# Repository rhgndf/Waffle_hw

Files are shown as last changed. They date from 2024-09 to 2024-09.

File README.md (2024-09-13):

# Waffle: a pocket pager, LoRA transceiver and RF experimentation platform
Hardware designs for Waffle, a compact Pager and general RF multitool.

## Introduction
This is a reboot of a [project started in 2016](https://hackaday.io/project/11056-waffle-a-pocket-sized-digital-radio-system), aimed at creating a pocket-sized digital radio system. Due to a lack of clear objectives and motivation, this project never got any further. However, there is today a certain revival of POCSAG in the amateur radio community, with the [DAPNET project](http://hampager.de). No open-source pager design exist to this day. This project aims to bridge that gap, and bring an open design that could be adapted to anyone's needs. 

## Feature list

 - UHF (430-440) support
 - User interface with three buttons and an easy-to-read display
 - Programmable either via the display, or via Wifi and web portal. 

## Hardware
Uses an ESP32-S3, coupled with an SX1276 for reception and transmission of signals. Battery is a classic 3.7V Li-Ion cell with integrated battery management and charging. USB-C port for programming and charging. OLED or LCD display (TBD).

## Hardware revision list

 - The [initial design from 2016](https://hackaday.io/project/11056-waffle-a-pocket-sized-digital-radio-system) is known as rev XX
 - 0.1a: current version. Aims to validate the basic hardware choices and being dev on software.

## Software
The (WIP) software can be found in [this repository](https://github.com/Jankyneering/Waffle_sw).

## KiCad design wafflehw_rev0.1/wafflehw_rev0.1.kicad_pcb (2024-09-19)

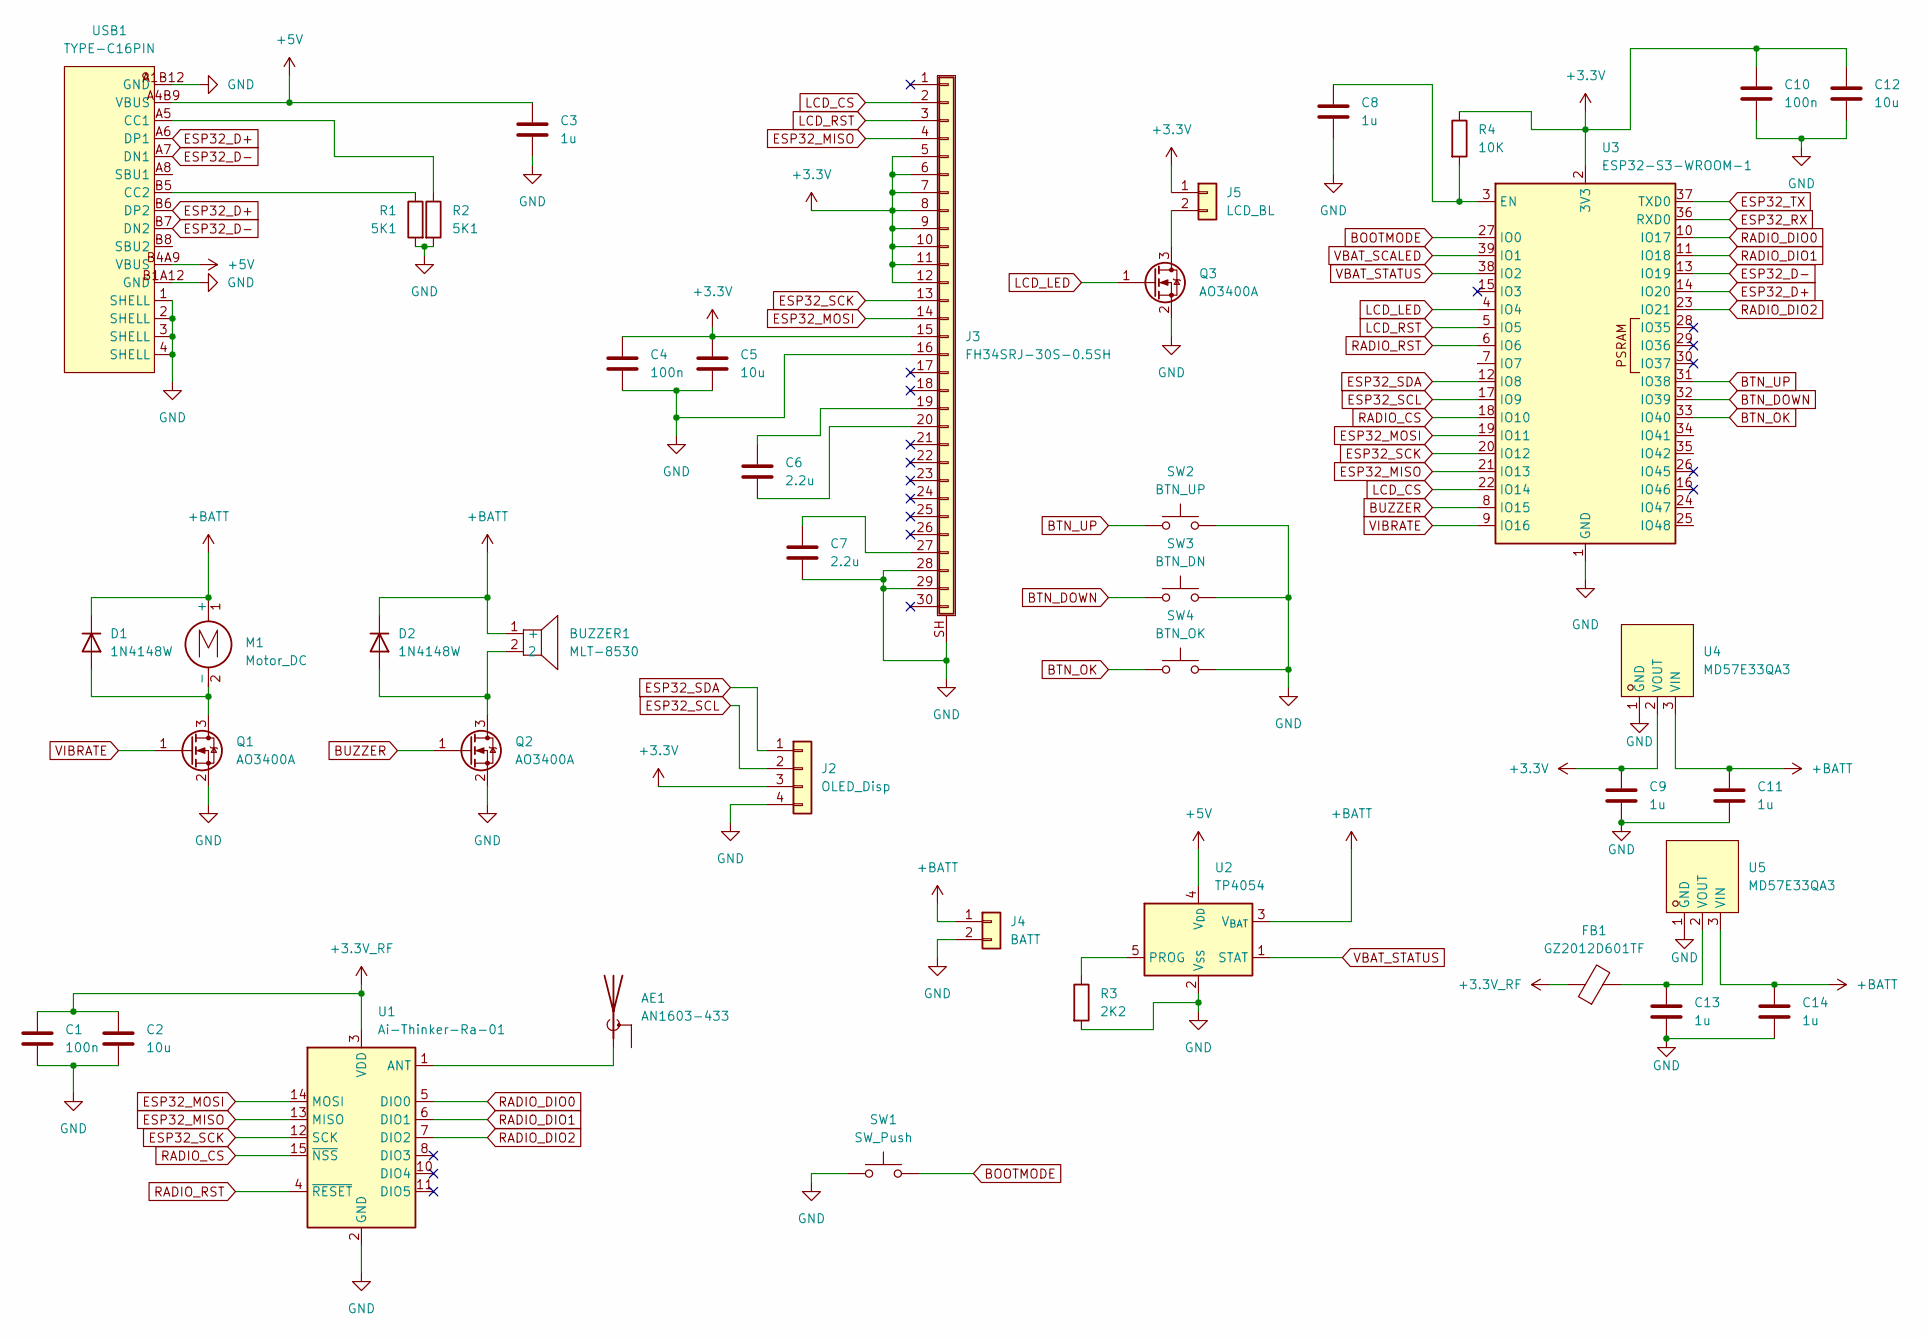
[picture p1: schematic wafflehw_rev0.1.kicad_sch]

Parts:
AE1: AN1603-433; Coilcraft_MA5532-AE_RFID
BUZZER1: MLT-8530; BUZ-SMD_4P-L8.5-W8.5-P8.50-BR; LCSC Part C94599
C1, C4, C10: 100n; C_0805_2012Metric
C2, C5, C12: 10u; C_0805_2012Metric
C3, C8, C9, C11, C13, C14: 1u; C_0805_2012Metric
C6, C7: 2.2u; C_0805_2012Metric
D1, D2: 1N4148W; D_SOD-123
FB1: GZ2012D601TF; L_0805_2012Metric
J2: OLED_Disp; PinHeader_1x04_P2.54mm_Vertical
J3: FH34SRJ-30S-0.5SH; ER-CON30HB-1
J4: BATT; ER-CON2.0-2P-SMD
J5: LCD_BL; ER-CON2.0-2P-SMD
M1: Motor_DC
Q1, Q2, Q3: AO3400A; SOT-23
R1, R2: 5K1; C_0805_2012Metric
R3: 2K2; C_0805_2012Metric
R4: 10K; C_0805_2012Metric
SW1: SW_Push; SW_SPST_CK_RS282G05A3
SW2: BTN_UP; SW_SPST_CK_RS282G05A3
SW3: BTN_DN; SW_SPST_CK_RS282G05A3
SW4: BTN_OK; SW_SPST_CK_RS282G05A3
U1: Ai-Thinker-Ra-01; Ai-Thinker-Ra-01-LoRa
U2: TP4054; SOT-23-5
U3: ESP32-S3-WROOM-1
U4, U5: MD57E33QA3; SOT-23-3_L2.9-W1.6-P1.90-LS2.8-BR; LCSC Part C920553
USB1: TYPE-C16PIN; USB-C-SMD_TYPE-C16PIN; LCSC Part C393939

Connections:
+3.3V: C4.1, C5.1, C9.1, C10.1, C12.1, J2.3, J3.5, J3.6, J3.7, J3.8, J3.9, J3.10, J3.11, J3.12, J3.15, J5.1, R4.1, U3.2 (3V3), U4.2 (VOUT)
+3.3V_RF: C1.1, C2.1, FB1.1, U1.3 (VDD)
+5V: C3.1, U2.4 (V_{DD}), USB1.A4B9 (VBUS), USB1.B4A9 (VBUS)
+BATT: BUZZER1.1 (+), C11.1, C14.1, D1.1 (K), D2.1 (K), J4.1, M1.1 (+), U2.3 (V_{BAT}), U4.3 (VIN), U5.3 (VIN)
BOOTMODE: SW1.2, U3.27 (IO0)
BTN_DOWN: SW3.1, U3.32 (IO39)
BTN_OK: SW4.1, U3.33 (IO40)
BTN_UP: SW2.1, U3.31 (IO38)
BUZZER: Q2.1 (G), U3.8 (IO15)
ESP32_D+: U3.14 (IO20), USB1.A6 (DP1), USB1.B6 (DP2)
ESP32_D-: U3.13 (IO19), USB1.A7 (DN1), USB1.B7 (DN2)
ESP32_MISO: J3.4, U1.13 (MISO), U3.21 (IO13)
ESP32_MOSI: J3.14, U1.14 (MOSI), U3.19 (IO11)
ESP32_RX: U3.36 (RXD0)
ESP32_SCK: J3.13, U1.12 (SCK), U3.20 (IO12)
ESP32_SCL: J2.2, U3.17 (IO9)
ESP32_SDA: J2.1, U3.12 (IO8)
ESP32_TX: U3.37 (TXD0)
GND: C1.2, C2.2, C3.2, C4.2, C5.2, C7.2, C8.2, C9.2, C10.2, C11.2, C12.2, C13.2, C14.2, J2.4, J3.16, J3.28, J3.29, J3.SH (Shield), J4.2, Q1.2 (S), Q2.2 (S), Q3.2 (S), R1.2, R2.2, R3.2, SW1.1, SW2.2, SW3.2, SW4.2, U1.2 (GND), U1.9 (GND), U1.16 (GND), U2.2 (V_{SS}), U3.1 (GND), U3.40 (GND), U3.41 (GND), U4.1 (GND), U5.1 (GND), USB1.1 (SHELL), USB1.2 (SHELL), USB1.3 (SHELL), USB1.4 (SHELL), USB1.A1B12 (GND), USB1.B1A12 (GND)
LCD_CS: J3.2, U3.22 (IO14)
LCD_LED: Q3.1 (G), U3.4 (IO4)
LCD_RST: J3.3, U3.5 (IO5)
unnamed: AE1.1 (A), U1.1 (ANT)
unnamed: D1.2 (A), M1.2 (-), Q1.3 (D)
unnamed: BUZZER1.2, D2.2 (A), Q2.3 (D)
unnamed: C6.1, J3.19
unnamed: C6.2, J3.20
unnamed: C7.1, J3.27
unnamed: J5.2, Q3.3 (D)
unnamed: R3.1, U2.5 (PROG)
unnamed: C8.1, R4.2, U3.3 (EN)
unnamed: C13.1, FB1.2, U5.2 (VOUT)
unnamed: R2.1, USB1.A5 (CC1)
unnamed: R1.1, USB1.B5 (CC2)
RADIO_CS: U1.15 (~NSS), U3.18 (IO10)
RADIO_DIO0: U1.5 (DIO0), U3.10 (IO17)
RADIO_DIO1: U1.6 (DIO1), U3.11 (IO18)
RADIO_DIO2: U1.7 (DIO2), U3.23 (IO21)
RADIO_RST: U1.4 (~RESET), U3.6 (IO6)
VBAT_SCALED: U3.39 (IO1)
VBAT_STATUS: U2.1 (STAT), U3.38 (IO2)
VIBRATE: Q1.1 (G), U3.9 (IO16)

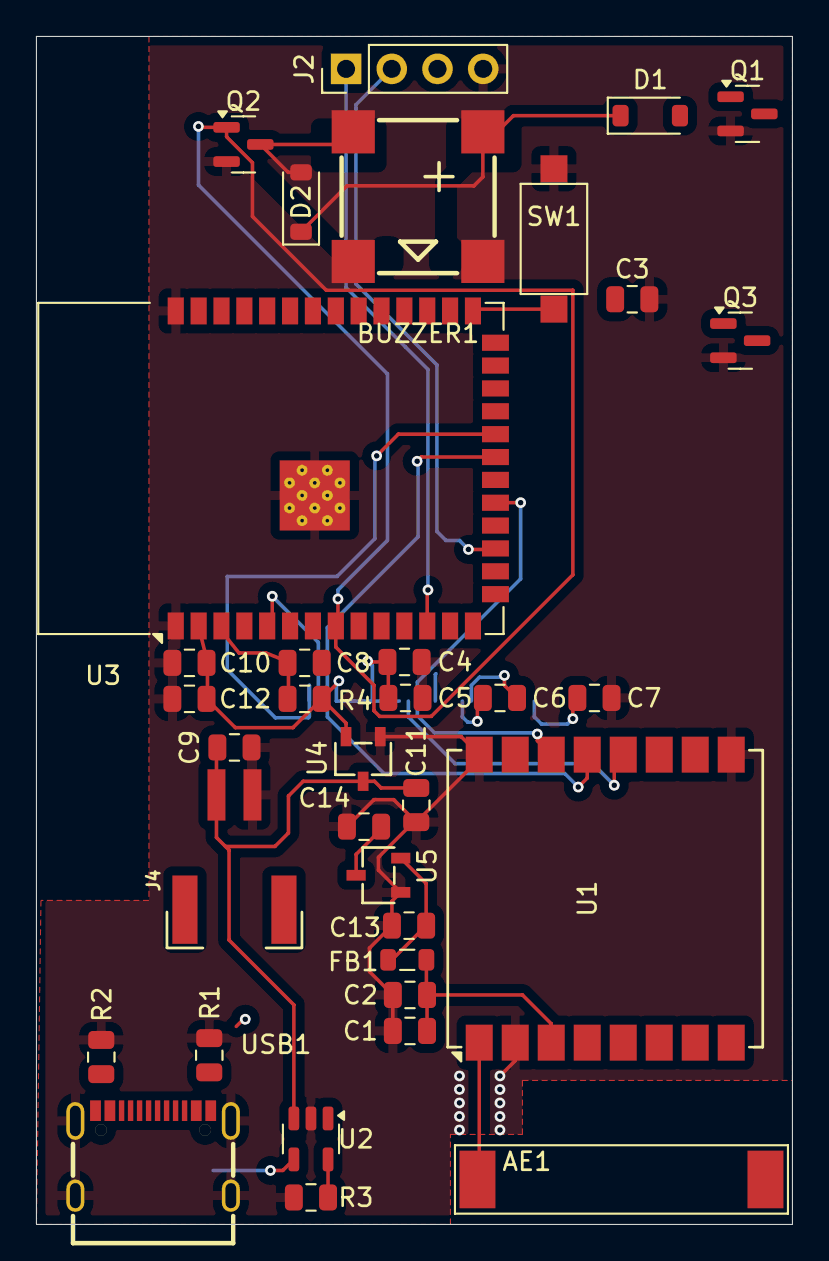
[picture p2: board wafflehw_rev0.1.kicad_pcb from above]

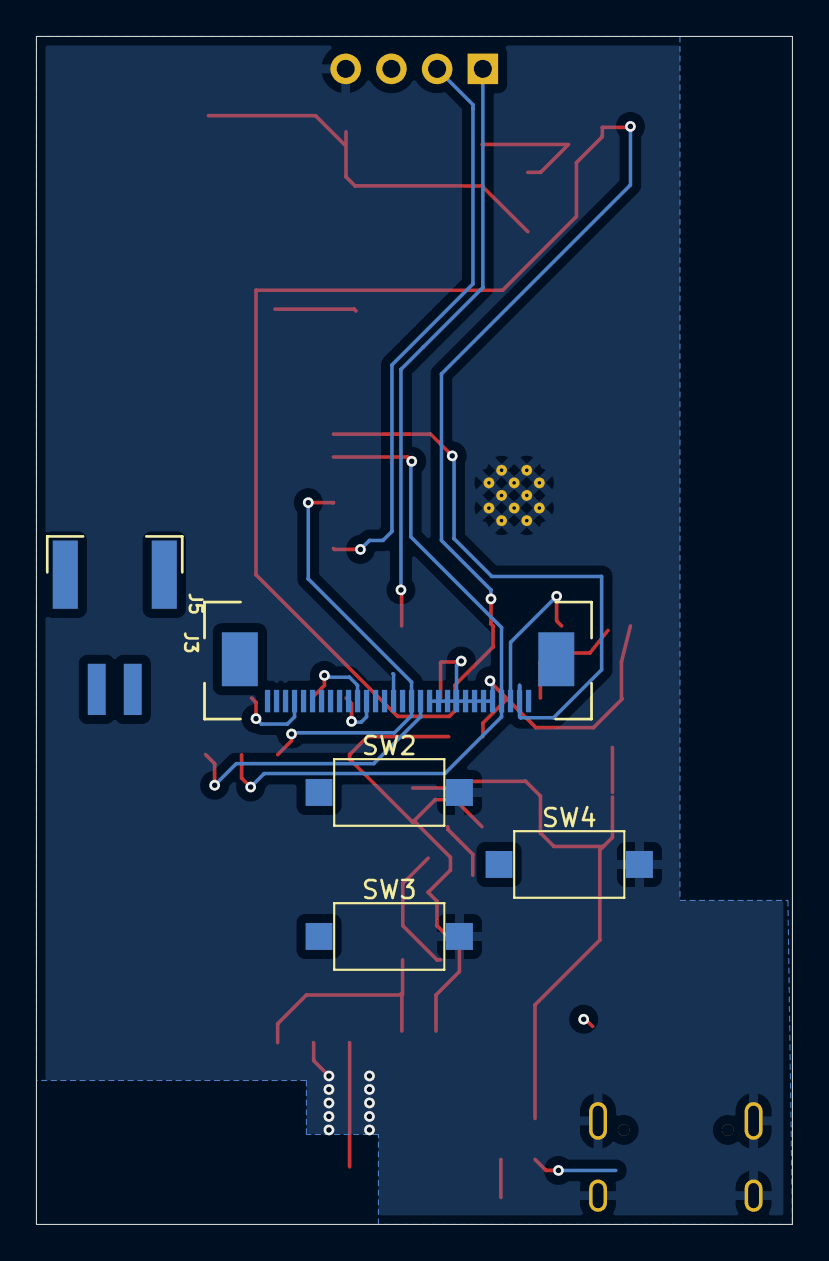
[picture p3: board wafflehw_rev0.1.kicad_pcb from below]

Board: 2 copper layers, 42.0 x 66.0 mm, 40 parts (5 on the bottom side), 39 nets.

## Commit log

2024-09-13 Initial Commit
    Added wip design for rev 0.1
    [wafflehw_rev0.1.kicad_pcb, wafflehw_rev0.1.kicad_sch]
2024-09-19 Schematic improvements
    [wafflehw_rev0.1.kicad_pcb, wafflehw_rev0.1.kicad_sch]
